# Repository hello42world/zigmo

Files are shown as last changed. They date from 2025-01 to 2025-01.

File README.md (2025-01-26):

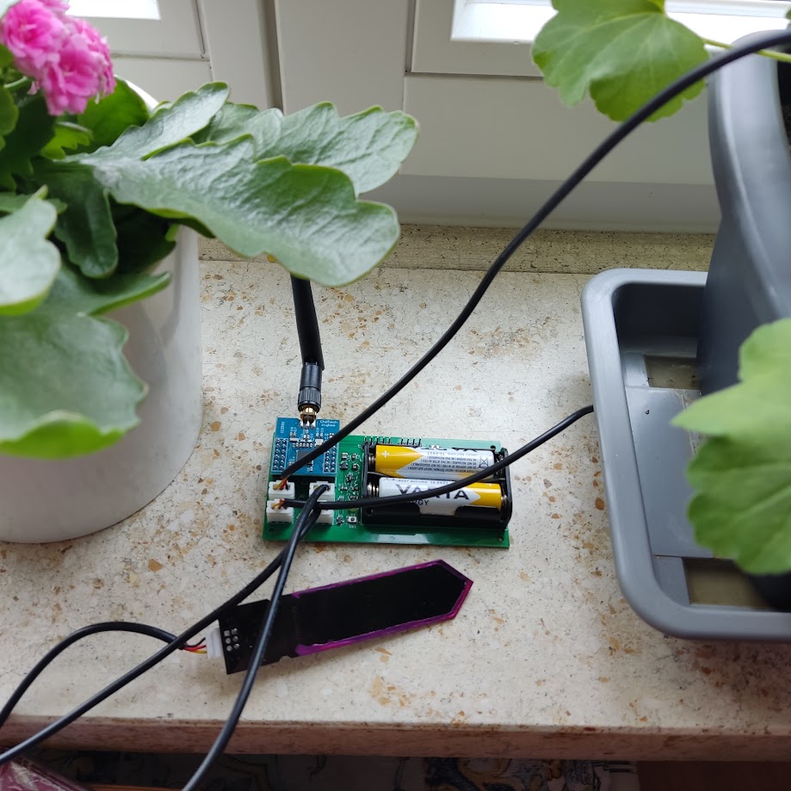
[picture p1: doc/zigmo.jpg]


# Intro
ZigMo is a 4 channel Zigbee soil moisture meter.  The project pursues 2 goals:
* Hardware: Attempt some very basic electric engineering and build a Zigbee device based on a custom PCB.
* Software: Write a custom firmware for the device that would make the Zigbee thing work.  

# Description
The concept is pretty simple. It is a Zigbee end device with 4 capacitive wire connected moisture sensors that you could stick into 4 nearby flower pots and monitor moisture levels in all of them with a single device.

This is what it looks like in Home Assistant:
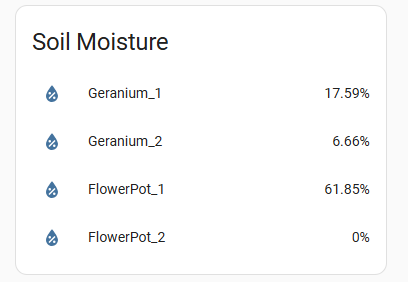
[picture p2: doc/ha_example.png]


The device is based on a popular CC2530 module that can be bought off Aliexpress for about $3. Custom PCB part handles battery power, routes connections to individual moisture sensors, provides debug connectors and implements user interface - a LED and a button.

# Build notes
### PCB:
The PCB was designed in KiCad and then ordered from JLCPCB. All parts are common and can be ordered from your favorite parts supplier.

**Note**: I know nothing about electric engineering and have no experience with PCB design. I just watched some video on Youtube on how to do it.

### Firmware:
The firmware is based on Zstack 3.0.2. It simply queries the moisture sensors and measures battery voltage every 5 minutes.

ZStack SDK is available for free from Texas Instruments. It contains several examples and even a guide on how to branch your own project off one of those examples (Z-Stack 3.0 Sample Application User's Guide.pdf). 
The most challenging part IMO is getting the IDE/Compiler. ZStack 3.0.2 applications should be built using IAR studio for 8051 processors version 10.20. This IDE is not free, however a free trial is available. You may find other ways of getting it if you search hard enough.

# See also
- Book: Drew Gislason - "Zigbee Wireless Networking"
- Very cool and super detailed series of posts on how to build a Zigbee device from scratch based on the NXP Zigbee stack: https://github.com/grafalex82/hellozigbee
- A bunch of ZStack Zigbee projects built at very professional level: https://github.com/diyruz

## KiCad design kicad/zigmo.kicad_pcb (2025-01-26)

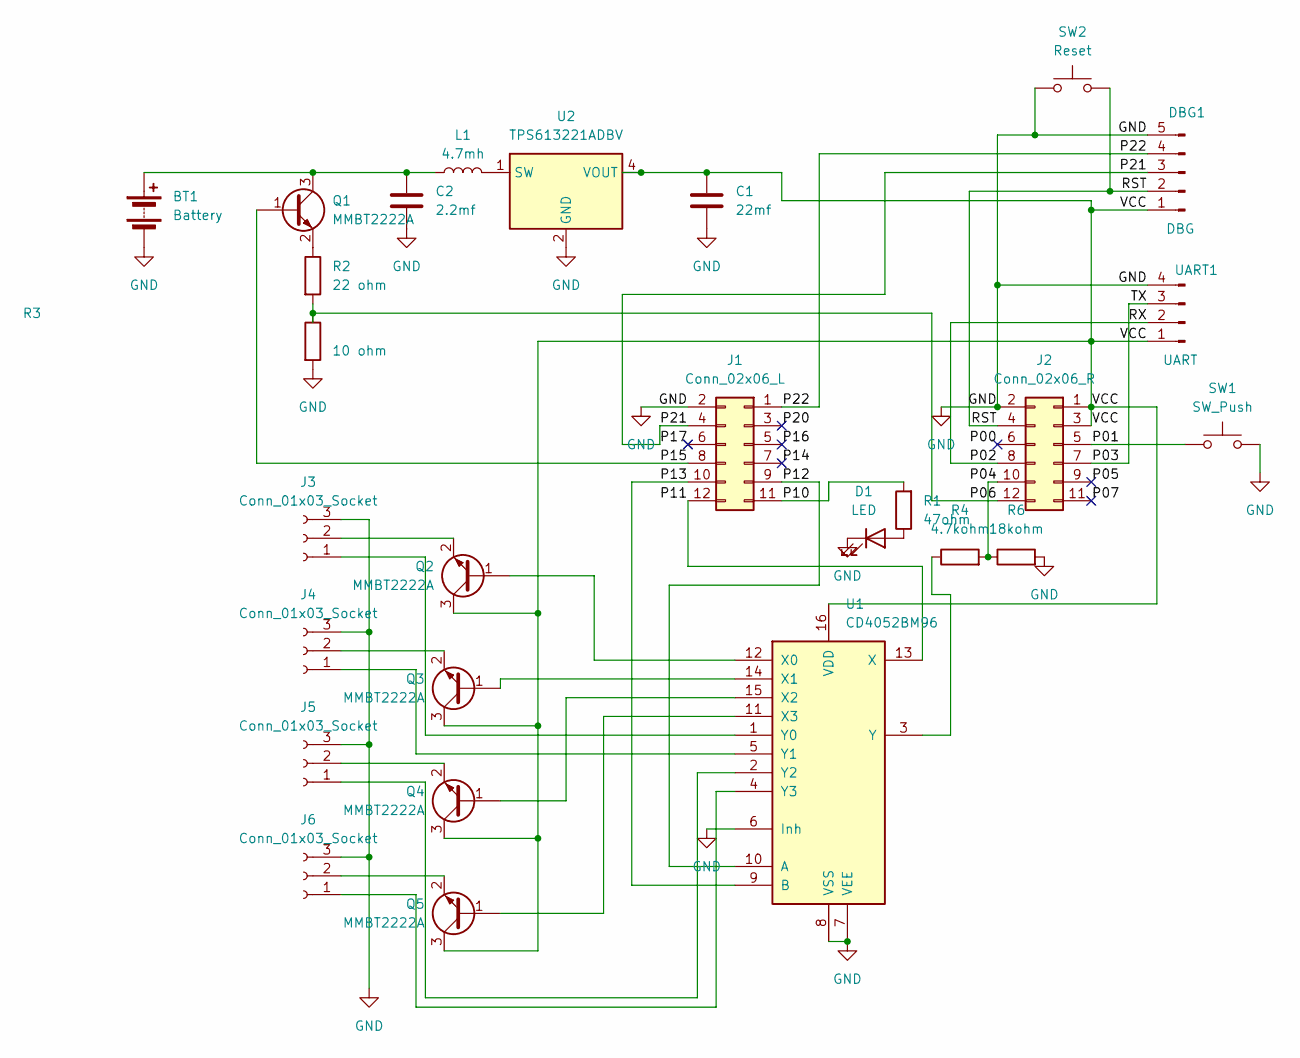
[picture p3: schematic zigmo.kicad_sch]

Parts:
BT1: Battery; BatteryHolder_Keystone_2462_2xAA
C1: 22mf; C_0805_2012Metric_Pad1.18x1.45mm_HandSolder
C2: 2.2mf; C_0805_2012Metric_Pad1.18x1.45mm_HandSolder
D1: LED; LED_D3.0mm
DBG1: DBG; PinHeader_1x05_P2.54mm_Vertical
J1: Conn_02x06_L; PinSocket_2x06_P2.54mm_Vertical
J2: Conn_02x06_R; PinSocket_2x06_P2.54mm_Vertical
J3, J4, J5, J6: Conn_01x03_Socket; JST_XH_B3B-XH-A_1x03_P2.50mm_Vertical
L1: 4.7mh; L_1008_2520Metric_Pad1.43x2.20mm_HandSolder
Q1, Q2, Q3, Q4, Q5: MMBT2222A; SOT-23
R1: 47ohm; R_0805_2012Metric_Pad1.20x1.40mm_HandSolder
R2: 22 ohm; R_0805_2012Metric_Pad1.20x1.40mm_HandSolder
R3: 10 ohm; R_0805_2012Metric_Pad1.20x1.40mm_HandSolder
R4: 4.7kohm; R_0805_2012Metric_Pad1.20x1.40mm_HandSolder
R6: 18kohm; R_0805_2012Metric_Pad1.20x1.40mm_HandSolder
SW1: SW_Push; SW_SPST_B3U-1000P
SW2: Reset; SW_SPST_B3U-1000P
U1: CD4052BM96; SO-16_3.9x9.9mm_P1.27mm
U2: TPS613221ADBV; SOT-23-5
UART1: UART; PinHeader_1x04_P2.54mm_Vertical

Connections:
/P00: J2.6
/P01: J2.5, SW1.1
/P02: J2.8, UART1.2; also elsewhere on the board
/P03: J2.7, UART1.3; also elsewhere on the board
/P04: J2.10, R4.2, R6.1
/P05: J2.9
/P06: J2.12, R2.2, R3.1
/P07: J2.11
/P10: J1.11, R1.2
/P11: J1.12, U1.13 (X)
/P12: J1.9, U1.10 (A)
/P13: J1.10, U1.9 (B)
/P14: J1.7
/P15: J1.8, Q1.1 (B)
/P16: J1.5
/P17: J1.6
/P20: J1.3
/P21: DBG1.3, J1.4; also elsewhere on the board
/P22: DBG1.4, J1.1; also elsewhere on the board
/RST: DBG1.2, J2.4, SW2.2; also elsewhere on the board
/VCC: C1.1, DBG1.1, J2.1, J2.3, Q2.3 (C), Q3.3 (C), Q4.3 (C), Q5.3 (C), U1.16 (VDD), U2.4 (VOUT), UART1.1; also elsewhere on the board
GND: BT1.2 (-), C1.2, C2.2, D1.1 (K), DBG1.5, J1.2, J2.2, J3.3, J4.3, J5.3, J6.3, R3.2, R6.2, SW1.2, SW2.1, U1.6 (Inh), U1.7 (VEE), U1.8 (VSS), U2.2 (GND), UART1.4; also elsewhere on the board
unnamed: BT1.1 (+), C2.1, L1.1, Q1.3 (C)
unnamed: D1.2 (A), R1.1
unnamed: J3.1, U1.1 (Y0)
unnamed: J3.2, Q2.2 (E)
unnamed: J4.1, U1.5 (Y1)
unnamed: J4.2, Q3.2 (E)
unnamed: J5.1, U1.2 (Y2)
unnamed: J5.2, Q4.2 (E)
unnamed: J6.1, U1.4 (Y3)
unnamed: J6.2, Q5.2 (E)
unnamed: Q1.2 (E), R2.1
unnamed: Q2.1 (B), U1.12 (X0)
unnamed: Q3.1 (B), U1.14 (X1)
unnamed: Q4.1 (B), U1.15 (X2)
unnamed: Q5.1 (B), U1.11 (X3)
unnamed: R4.1, U1.3 (Y)
unnamed: L1.2, U2.1 (SW)

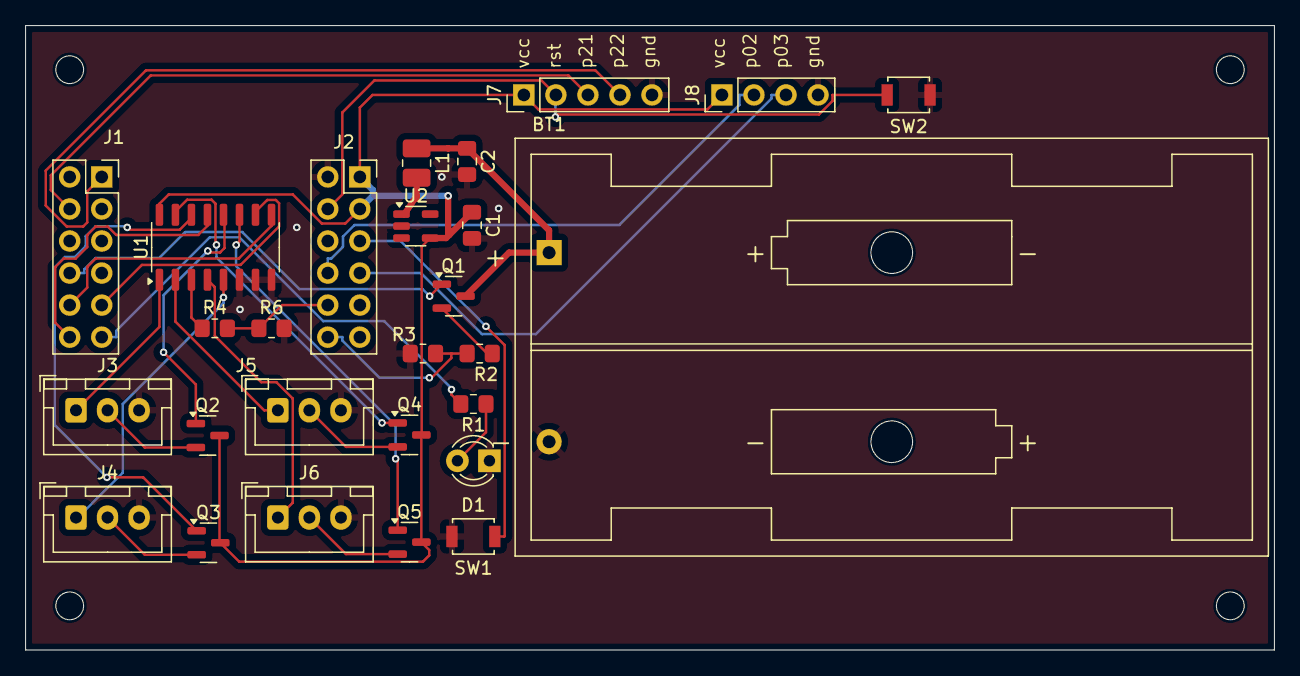
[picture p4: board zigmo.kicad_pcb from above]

Board: 2 copper layers, 99.0 x 49.5 mm, 31 parts (0 on the bottom side), 32 nets.

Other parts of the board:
J7: DBG; PinHeader_1x05_P2.54mm_Vertical
J8: UART; PinHeader_1x04_P2.54mm_Vertical
REF1, REF2, REF3, REF4: MountingHole_2.2mm_M2

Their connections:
/P02: J8.2; also elsewhere on the board
/P03: J8.3; also elsewhere on the board
/P21: J7.3; also elsewhere on the board
/P22: J7.4; also elsewhere on the board
/RST: J7.2; also elsewhere on the board
/VCC: J7.1, J8.1; also elsewhere on the board
GND: J7.5, J8.4; also elsewhere on the board

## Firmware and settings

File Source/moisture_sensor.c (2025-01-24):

#include "moisture_sensor.h"

#include "hal2.h"

#include "OnBoard.h"
#include "zcl_ha.h"
#include "bdb.h"
#include "bdb_interface.h"
#include "hal_adc.h"
#include "dbg.h"

#define ZIGMO_NUM_SENSOR_ZCL_ATTR 4

#define ZIGMO_DECLARE_SENSOR_ZCL_ATTRS(measured_val_ptr) \
{ \
  { \
    ZCL_CLUSTER_ID_MS_RELATIVE_HUMIDITY, \
    { \
      ATTRID_MS_RELATIVE_HUMIDITY_MEASURED_VALUE, \
      ZCL_DATATYPE_UINT16, \
      ACCESS_CONTROL_READ | ACCESS_REPORTABLE, \
      (void *)measured_val_ptr \
    } \
  }, \
  { \
    ZCL_CLUSTER_ID_MS_RELATIVE_HUMIDITY, \
    { \
      ATTRID_MS_RELATIVE_HUMIDITY_MIN_MEASURED_VALUE, \
      ZCL_DATATYPE_UINT16, \
      ACCESS_CONTROL_READ, \
      (void *)&zclZigmoHumidity_MinMeasuredValue \
    } \
  }, \
  { \
    ZCL_CLUSTER_ID_MS_RELATIVE_HUMIDITY, \
    { \
      ATTRID_MS_RELATIVE_HUMIDITY_MAX_MEASURED_VALUE, \
      ZCL_DATATYPE_UINT16, \
      ACCESS_CONTROL_READ, \
      (void *)&zclZigmoHumidity_MaxMeasuredValue \
    } \
  }, \
  { \
    ZCL_CLUSTER_ID_MS_RELATIVE_HUMIDITY, \
    { \
      ATTRID_CLUSTER_REVISION, \
      ZCL_DATATYPE_UINT16, \
      ACCESS_CONTROL_READ, \
      (void *)&zigmo_cluster_revision \
    } \
  } \
}

const int16 zclZigmoHumidity_MinMeasuredValue = 0;
const int16 zclZigmoHumidity_MaxMeasuredValue = 10000;
const uint16 zigmo_cluster_revision = 0x0001;

static const cId_t _InClusterList[] =
{
  ZCL_CLUSTER_ID_MS_RELATIVE_HUMIDITY
};


// Sensor array

ZigmoSensorEndpoint g_zigmo_endpoints[ZIGMO_NUM_SENSORS];

CONST zclAttrRec_t g_zigmo_sensor_attrs[][ZIGMO_NUM_SENSOR_ZCL_ATTR] = {
  ZIGMO_DECLARE_SENSOR_ZCL_ATTRS(&g_zigmo_endpoints[0].measuredValue),
  ZIGMO_DECLARE_SENSOR_ZCL_ATTRS(&g_zigmo_endpoints[1].measuredValue),
  ZIGMO_DECLARE_SENSOR_ZCL_ATTRS(&g_zigmo_endpoints[2].measuredValue),
  ZIGMO_DECLARE_SENSOR_ZCL_ATTRS(&g_zigmo_endpoints[3].measuredValue),
/*
  ZIGMO_DECLARE_SENSOR_ZCL_ATTRS(&g_zigmo_endpoints[4].measuredValue),
  ZIGMO_DECLARE_SENSOR_ZCL_ATTRS(&g_zigmo_endpoints[5].measuredValue),
  ZIGMO_DECLARE_SENSOR_ZCL_ATTRS(&g_zigmo_endpoints[6].measuredValue),
  ZIGMO_DECLARE_SENSOR_ZCL_ATTRS(&g_zigmo_endpoints[7].measuredValue),
*/
};

// Number of attrs in zigmo_sensor_attrs must == NUM_SENSORS
STATIC_ASSERT(
              (sizeof(g_zigmo_sensor_attrs) / sizeof(zclAttrRec_t) / ZIGMO_NUM_SENSOR_ZCL_ATTR) == ZIGMO_NUM_SENSORS,
              num_attr_mismatch_w_sensors);

STATIC_ASSERT(BDBREPORTING_MAX_ANALOG_ATTR_SIZE == 4, Wrong_bdb_attr_size);
// 500 or 5% is the min reportable change.
uint8 moistureReportableChange[] = {0xF4, 0x01, 0x00, 0x00};

static ZStatus_t zigmo_sensor_register_endpoint(
  ZigmoSensorEndpoint* ep,
  uint8 endpoint_id,
  zclGeneral_AppCallbacks_t* cmd_callbacks)
{
  ZStatus_t s;

  bdb_RegisterSimpleDescriptor(&ep->simpleDesc);

  s = zclGeneral_RegisterCmdCallbacks(endpoint_id, cmd_callbacks );
  if (s != ZSuccess) {
    return s;
  }

  s = zcl_registerAttrList(endpoint_id,
                           ZIGMO_NUM_SENSOR_ZCL_ATTR,
                           ep->pAttrs );
  if (s != ZSuccess) {
    return s;
  }

  s = bdb_RepAddAttrCfgRecordDefaultToList(
   endpoint_id,
   ZCL_CLUSTER_ID_MS_RELATIVE_HUMIDITY,
   ATTRID_MS_RELATIVE_HUMIDITY_MEASURED_VALUE,
   0,   // No min report interval.
   600, // Max inteval is every 10 min.
   moistureReportableChange);
  return s;
}

static ZStatus_t zigmo_moisture_sensor_init_endpoint(
  ZigmoSensorEndpoint* ep,
  uint8 endpoint_id,
  const zclAttrRec_t __code* attrs,
  zclGeneral_AppCallbacks_t* cmd_callbacks)
{
  // Init attrs
  ep->pAttrs = attrs;

  // Init simple descriptor
  ep->simpleDesc.EndPoint = endpoint_id;
  ep->simpleDesc.AppProfId = ZCL_HA_PROFILE_ID;
  ep->simpleDesc.AppDeviceId = ZCL_HA_DEVICEID_SIMPLE_SENSOR;
  ep->simpleDesc.AppDevVer = 1;
  ep->simpleDesc.Reserved = 0;
  ep->simpleDesc.AppNumInClusters = 1;
  ep->simpleDesc.pAppInClusterList = (cId_t*) _InClusterList;
  ep->simpleDesc.AppNumOutClusters = 0;
  ep->simpleDesc.pAppOutClusterList = NULL;


  // Init measured value
  ep->measuredValue = 0;

  return zigmo_sensor_register_endpoint(ep, endpoint_id, cmd_callbacks);
}

ZStatus_t zigmo_moisture_sensor_init_sensors(
  uint8 first_endpoint_num,
  zclGeneral_AppCallbacks_t* cmd_callbacks)
{
  //
  // Init pins
  //

  // Sensor power pin
  // Set P1_1 to GPIO
  P1SEL &= ~(1 << 1);
  // Set P1_1 direction to Output.
  P1DIR |= (1 << 1);

  // Channel select pin 0
  // Set P1_2 to GPIO
  P1SEL &= ~(1 << 2);
  // Set P1_1 direction to Output.
  P1DIR |= (1 << 2);

  // Channel select pin 1
  // Set P1_3 to GPIO
  P1SEL &= ~(1 << 3);
  // Set P1_3 direction to Output.
  P1DIR |= (1 << 3);

  // Sensor ADC pin
  // Enable ADC on P0_4
  APCFG |= (1 << 4);

  //
  // Init endpoints
  //
  for (uint8 i = 0; i < ZIGMO_NUM_SENSORS; i++)
  {
    ZStatus_t s = zigmo_moisture_sensor_init_endpoint(
      &g_zigmo_endpoints[i],
      first_endpoint_num + i,
      g_zigmo_sensor_attrs[i],
      cmd_callbacks);
    if (s != ZSuccess) {
      return s;
    }
  }

  return ZSuccess;
}

// 10 bit ADC
//#define ADC_MAX 250
//#define ADC_MIN 110

// 12 bit ADC
#define ADC_MAX 1300
#define ADC_MIN 760


static int16 zigmo_moisture_sensor_read(uint8 sensor_num)
{
  // Enable the corresponding multiplexer channel.
  ZIGMO_SENSOR_SEL_A_PIN = (sensor_num >> 0) & 0x01; // A
  ZIGMO_SENSOR_SEL_B_PIN = (sensor_num >> 1) & 0x01; // B

  zigmo_util_delay(4000);

  int32 adc;
  int32 ksave0 = 0;

  /* Keep on reading the ADC until two consecutive key decisions are the same. */
  do
  {
    ksave0 = adc;
    adc = HalAdcRead (HAL_ADC_CHN_AIN4, HAL_ADC_RESOLUTION_12);
  } while (adc != ksave0);

  if (adc < 60) {
    return 0; // No input signal.
  }

  if (adc < ADC_MIN) adc = ADC_MIN;
  if (adc > ADC_MAX) adc = ADC_MAX;

  adc = (ADC_MAX - adc) * 100 * 100  / (ADC_MAX - ADC_MIN);

  return (int16)adc;
}


void zigmo_moisture_sensors_refresh(uint8 first_endpoint_num)
{
  HalAdcSetReference(HAL_ADC_REF_125V);
  ZIGMO_SENSOR_PWR_PIN = 1; // Power on the sensor circuit.

  for (int i = 0; i < ZIGMO_NUM_SENSORS; i++)
  {
    g_zigmo_endpoints[i].measuredValue = zigmo_moisture_sensor_read(i);

    bdb_RepChangedAttrValue(
      first_endpoint_num + i,
      ZCL_CLUSTER_ID_MS_RELATIVE_HUMIDITY,
      ATTRID_MS_RELATIVE_HUMIDITY_MEASURED_VALUE);
  }
  ZIGMO_SENSOR_PWR_PIN = 0;
/*
  dprintf("%d %d %d %d",
          g_zigmo_endpoints[0].measuredValue,
          g_zigmo_endpoints[1].measuredValue,
          g_zigmo_endpoints[2].measuredValue,
          g_zigmo_endpoints[3].measuredValue);
*/
}

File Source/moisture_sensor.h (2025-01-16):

#ifndef ZIGMO_MOISTURE_SENSOR_H
#define ZIGMO_MOISTURE_SENSOR_H

#include "util.h"

#include "zcl.h"
#include "zcl_ms.h"
#include "zcl_general.h"


// Defines
#define ZIGMO_SENSOR_PWR_PIN   P1_1
#define ZIGMO_SENSOR_SEL_A_PIN P1_2
#define ZIGMO_SENSOR_SEL_B_PIN P1_3

#define ZIGMO_NUM_SENSORS 4


// Typedefs

typedef struct {
  const __code zclAttrRec_t* pAttrs;
  SimpleDescriptionFormat_t simpleDesc;
  int16 measuredValue;
} ZigmoSensorEndpoint;


// Vars

extern const int16 zclZigmoHumidity_MinMeasuredValue;
extern const int16 zclZigmoHumidity_MaxMeasuredValue;
//extern CONST zclAttrRec_t g_zigmo_sensor_attrs[][ZIGMO_NUM_SENSOR_ZCL_ATTR];

// Functions.

ZStatus_t zigmo_moisture_sensor_init_sensors(
  uint8 first_endpoint_num,
  zclGeneral_AppCallbacks_t* cmd_callbacks);

extern void zigmo_moisture_sensors_refresh(uint8 first_endpoint_num);


#endif

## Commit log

2024-07-03 Initial sketch of sensor array code
2024-07-03 Try multiple sensors in array
2024-07-07 Sensor value update works (dummy)
2024-07-29 Dummy attr update (on timer)
2024-08-04 Restart button impl with fresh HAL copy
2024-08-13 Played with a button and a led
2024-08-14 Button scan fix + code cleanup
    [hal2.c, zcl_zigmo.c]
2024-08-15 Button long press implemented
2024-09-22 Played with ADC
2024-10-13 Test using ADC AIN7 ref + code cleanup.
2024-10-13 Set ADC ref in read function.
2024-10-13 Played with batt voltage meter
2024-10-16 Battery measuring enabled
2024-11-03 debug print added
2024-11-04 Button handling reworked
2024-11-07 All sensor code extracted
2024-11-09 Led blink implemented
2025-01-16 Code cleanup and fixes.
    [hal2.c, moisture_sensor.c, moisture_sensor.h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]
2025-01-23 Fix binding array size
    [moisture_sensor.c, zcl_zigmo.c]
2025-01-23 Tried addind a second sensor
2025-01-23 Mem optimized. XDATA error gone.
    [zcl_zigmo.c]
2025-01-23 Disable flow contol in MT
2025-01-26 KiCad files added
    [zigmo.kicad_pcb, zigmo.kicad_sch]
